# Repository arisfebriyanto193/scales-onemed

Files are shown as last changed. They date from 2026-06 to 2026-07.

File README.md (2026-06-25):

# scales-onemed

## Dokumentasi hardware: ./hadware.md

## Cara Menjalankan Program

### 1. Persiapan Database & Backend
Pastikan MySQL sudah berjalan di komputer Anda.

1. Buka terminal dan masuk ke folder `backend`:
   ```bash
   cd backend
   ```
2. Install semua dependencies:
   ```bash
   npm install
   ```
3. Buat file `.env` berdasarkan file contoh (salin isi `.env.example` ke file baru bernama `.env`):
   ```bash
   cp .env.example .env
   ```
   *Sesuaikan konfigurasi database (DB_USER, DB_PASSWORD, dll) di file `.env` jika diperlukan.*
4. Jalankan migrasi database untuk membuat tabel dan data awal (seeding):
   ```bash
   node migrations/run_migrations.js
   ```
5. Jalankan server backend:
   ```bash
   npm run dev
   ```
   *(Backend akan berjalan di port yang ditentukan di `.env`, biasanya `http://localhost:5000`)*

### 2. Persiapan Frontend
Buka tab terminal baru untuk menjalankan frontend.

1. Masuk ke folder `frontend`:
   ```bash
   cd frontend
   ```
2. Install semua dependencies:
   ```bash
   npm install
   ```
3. Pastikan ada file `.env.local` (jika diperlukan) untuk mengatur URL API backend (contoh: `NEXT_PUBLIC_API_URL=http://localhost:5000/api`).
4. Jalankan aplikasi frontend:
   ```bash
   npm run dev
   ```
   *(Frontend akan berjalan di port default Next.js, biasanya `http://localhost:3000`)*

Sekarang Anda bisa mengakses aplikasi melalui browser di `http://localhost:3000`.

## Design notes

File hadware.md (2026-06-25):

# Dokumentasi Hardware: Sistem Timbangan Pintar (ESP-A & ESP-B)

Dokumen ini menjelaskan arsitektur, hubungan, dan alur kerja antara dua mikrokontroler ESP32 (`espA` dan `espB`) yang digunakan dalam sistem timbangan pintar terintegrasi RFID dan IoT.

## 1. Hubungan ESP-A dan ESP-B

Kedua modul ESP32 ini memiliki peran yang dipisah (decoupled) agar kinerja sistem lebih stabil dan tidak saling membebani:
*   **ESP-A (Bluetooth Gateway):** Dikhususkan untuk menangani komunikasi Bluetooth Low Energy (BLE) yang seringkali intensif dan membutuhkan *real-time scanning*.
*   **ESP-B (Main Controller & IoT):** Berfungsi sebagai otak utama yang mengurus antarmuka pengguna (OLED), pembacaan identitas (RFID), dan komunikasi dua arah ke server (WiFi & WebSocket).

**Jalur Komunikasi:**
Kedua ESP ini berkomunikasi satu arah menggunakan pin **Serial UART (Hardware Serial2)**. 
*   **ESP-A (TX: GPIO17)** ──Kabel Data──> **ESP-B (RX: GPIO16)**
*   **ESP-A (GND)** ────────Kabel GND───> **ESP-B (GND)**

---

## 2. Skema Pin dan Wiring (Pinout)
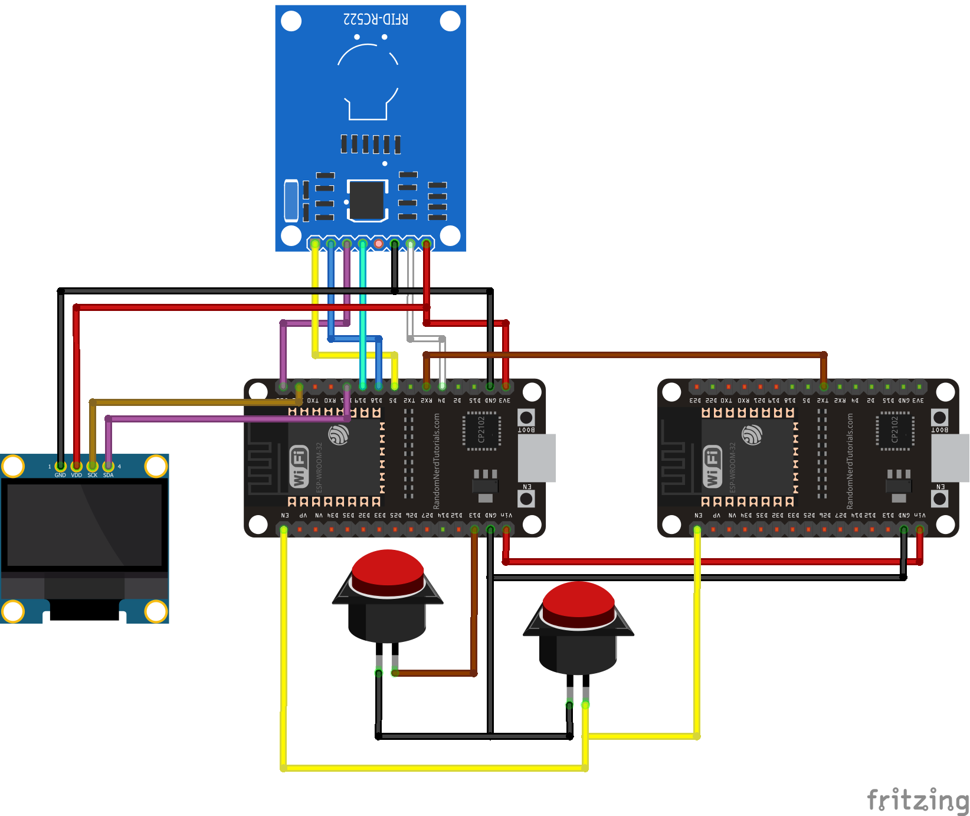
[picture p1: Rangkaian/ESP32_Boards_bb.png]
Rangkaian


Sistem ini menggunakan dua mikrokontroler ESP32 dengan pengkabelan sebagai berikut:

### Komunikasi Antar ESP32 (UART)
| ESP-A (Bluetooth) | ESP-B (Main Controller) | Keterangan |
| :--- | :--- | :--- |
| TX (GPIO 17) | RX (GPIO 16) | Mengirim data pengukuran |
| RX (GPIO 16) | TX (GPIO 17) | (Opsional, saat ini hanya searah) |
| GND | GND | Wajib disambung agar referensi tegangan sama |

### Modul RFID (RC522) -> ESP-B
Komunikasi menggunakan antarmuka **SPI**.
| Pin RC522 | Pin ESP-B | Keterangan |
| :--- | :--- | :--- |
| SDA / SS | GPIO 5 | Chip Select / Slave Select |
| SCK | GPIO 18 | Serial Clock |
| MOSI | GPIO 23 | Master Out Slave In |
| MISO | GPIO 19 | Master In Slave Out |
| RST | GPIO 4 | Reset (Jangan gunakan 22 karena dipakai OLED) |
| 3.3V | 3.3V | Power (Tegangan wajib 3.3V) |
| GND | GND | Ground |

### Layar OLED (SH1106 1.3" 128x64) -> ESP-B
Komunikasi menggunakan antarmuka **I2C**.
| Pin OLED | Pin ESP-B | Keterangan |
| :--- | :--- | :--- |
| SDA | GPIO 21 | Serial Data |
| SCL | GPIO 22 | Serial Clock |
| VCC | 3.3V | Power |
| GND | GND | Ground |

### Tombol (Push Button) -> ESP-B
| Pin Tombol | Pin ESP-B | Keterangan |
| :--- | :--- | :--- |
| Kaki 1 | GPIO 13 | Pin Input Pullup (Tombol HOLD/Reset) |
| Kaki 2 | GND | Trigger aktif LOW saat ditekan |

---

## 3. Fungsi dan Alur Kerja ESP-A (Pengambil Data BLE)

File: `espA.ino`

1.  **Scanning & Koneksi BLE:** ESP-A secara terus-menerus memindai perangkat BLE di sekitarnya untuk mencari timbangan dengan nama `SENSSUN Growth`. Setelah ditemukan, ESP-A akan melakukan koneksi ke perangkat tersebut.
2.  **Berlangganan Data (Notify):** Setelah terhubung, ESP-A mendengarkan (subscribe) pada karakteristik khusus (UUID: `0000fff1...`) untuk menerima notifikasi secara otomatis setiap kali timbangan mengukur atau datanya stabil.
3.  **Parsing Data Mentah (Hex):** Saat data masuk (`notifyCallback`), ESP-A menerima *array of bytes* (`uint8_t* data`) dari timbangan. Susunan data *byte* dari timbangan diurai sebagai berikut:
    *   **Berat Badan (kg):** Diambil dari index ke-2 dan ke-3 dalam *array* data (`data[2]` dan `data[3]`). Dua *byte* tersebut digabungkan (di-*shift* 8 bit) menjadi satu angka `uint16_t`, lalu dibagi `1000.0f` untuk mendapatkan angka aktual dalam satuan kilogram (kg).
    *   **Tinggi Badan (cm):** Diambil dari index ke-6 dan ke-7 (`data[6]` dan `data[7]`). Sama seperti berat, dua *byte* ini digabungkan menjadi `uint16_t` lalu dibagi `10.0f` untuk mendapatkan angka dalam satuan sentimeter (cm).
    *   **Kalkulasi BMI:** ESP-A akan menghitung *Body Mass Index* secara internal menggunakan rumus standar `BMI = Berat(kg) / (Tinggi(m) * Tinggi(m))`.
4.  **Pengiriman via UART:** Data yang sudah matang dan mudah dibaca kemudian dirakit menjadi satu baris teks sederhana (contoh: `BERAT:15.200;TINGGI:102.5;BMI:14.5\n`) lalu dikirimkan ke ESP-B melalui pin TX UART.

---

## 4. Fungsi dan Alur Kerja ESP-B (Main Controller & IoT)

File: `espB.ino`

ESP-B adalah titik kumpul dari semua fitur perangkat keras dan pengirim data akhir ke *cloud*. Berikut adalah penjabaran fungsinya:

### A. Mengambil Data RFID (MFRC522)
*   Menggunakan antarmuka **SPI** (Pin SCK=18, MISO=19, MOSI=23, SS=5).
*   Secara terus-menerus memantau apakah ada kartu atau *tag* RFID anak yang ditempelkan ke sensor.
*   Jika terdeteksi, ia membaca **UID (Unique ID)** kartu tersebut. Terdapat mekanisme *cooldown* 3 detik agar kartu yang sama tidak terbaca berkali-kali secara instan saat ditahan.

### B. Menampilkan di Layar (OLED SH1106)
*   Menggunakan antarmuka **I2C** (SDA=21, SCL=22).
*   Layar berfungsi sebagai indikator visual yang dinamis:
    *   **Status Sistem:** Menampilkan status koneksi WiFi, koneksi WebSocket, alamat IP, atau Mode AP saat awal dinyalakan.
    *   **Identifikasi Kartu:** Menampilkan UID Kartu saat baru saja di-tap dan menunggu respon server.
    *   **Nama Anak:** Menampilkan nama anak (selama 10 detik) setelah mendapatkan balasan/konfirmasi dari server IoT.
    *   **Data Pengukuran:** Menampilkan *Berat, Tinggi, dan BMI* yang dikirim dari ESP-A. Layar ini tampil jika tidak sedang mengutamakan tampilan nama anak.

### C. Komunikasi IoT (WebSocket)
ESP-B terhubung ke server *backend* menggunakan protokol **WebSocket (Secure / WSS)**. Ini membuat pertukaran data terjadi secara *real-time* dan sangat cepat.
1.  **Kirim UID:** Saat RFID di-tap, UID langsung dilempar ke server (Topik: `.../idcard|UID`).
2.  **Menerima Nama Anak:** Server memeriksa UID tersebut di database. Jika terdaftar, server membalas (mengirim topik `.../childname`) berisi nama anak yang bersangkutan. ESP-B menangkap data ini dan menampilkannya di OLED.
3.  **Kirim Data Timbangan:** Saat ESP-B menerima data teks ukur dari ESP-A melalui UART, ESP-B akan memecah (parse) kembali teks tersebut. Jika sistem tidak sedang di-*pause* (tombol HOLD mati), data tersebut langsung disiarkan ke server WebSocket satu per satu untuk topik berat, tinggi, dan bmi. Halaman web/frontend yang juga terhubung ke WebSocket akan langsung berkedip menampilkan angka ukur tanpa perlu me-refresh halaman.

### D. Fitur Tambahan (Konfigurasi & Tombol Pintar)
*   **WiFiManager:** Jika ESP-B baru dipasang atau gagal terhubung ke router WiFi, ia otomatis membuat Hotspot (AP Mode) bernama `ESP32_PENTING_Config`. Anda dapat terhubung ke *hotspot* ini melalui HP untuk mengatur SSID dan Password WiFi baru, serta mengisi konfigurasi alamat Server IoT (Host, Port, Prefix Topik). Setingan ini tersimpan di memori internal ESP.
*   **Tombol Fisik (GPIO 13):**
    *   **Tekan Singkat (< 5 detik):** Mengaktifkan/mematikan fitur **HOLD**. Jika fitur HOLD aktif, data angka dari timbangan akan *ditahan* dan tidak akan terkirim ke server (berguna ketika anak sedang banyak bergerak di atas timbangan sehingga angkanya belum akurat).
    *   **Tekan Lama (> 10 detik):** Melakukan **Factory Reset WiFi**. Alat akan menghapus memori WiFi yang tersimpan lalu *restart* untuk masuk kembali ke mode AP.

---

## 5. Desain Case (Perangkat Keras)

Berikut adalah rancangan 3D dari wadah (*case*) untuk merakit komponen-komponen *hardware* ke dalam satu kesatuan sistem:

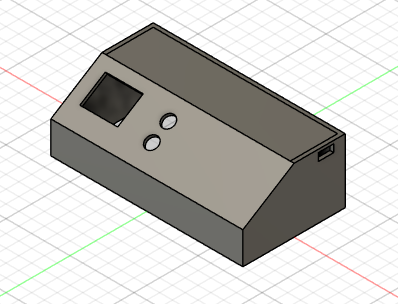
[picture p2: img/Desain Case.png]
Desain Case 1


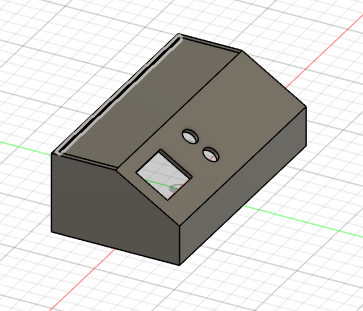
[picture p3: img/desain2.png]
Desain Case 2


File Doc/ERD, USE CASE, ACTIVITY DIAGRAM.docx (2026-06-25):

Login di Web

Manajemen User

Melihat Data Bayi

Keseluruhan di Web

Melihat Data

Bayi Pribadi

Mengedit Data Bayi

Keseluruhan di Web

Logout di Web

Melakukan Scan

RFID Bayi

Melakukan

Pengukuran Bayi

KADER

ADMIN

WARGA

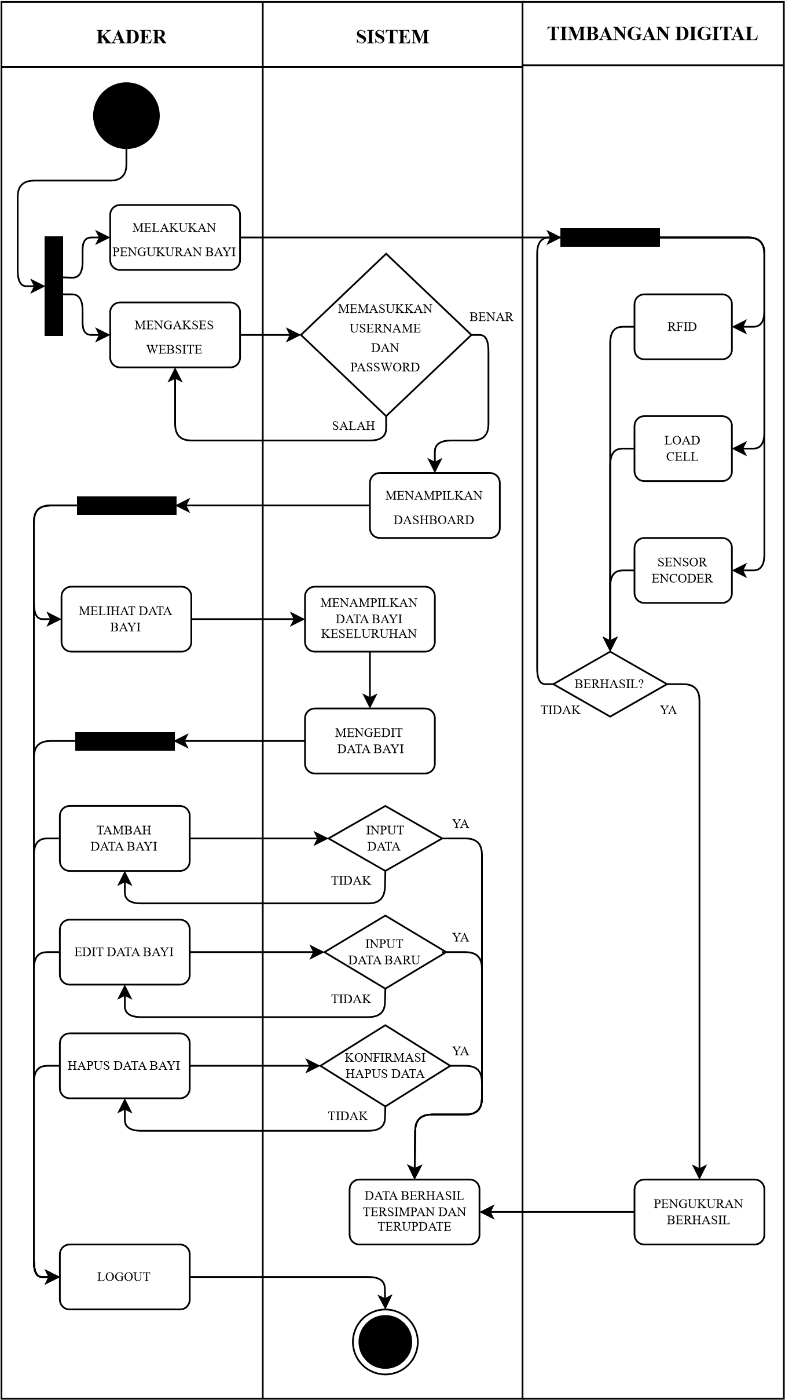
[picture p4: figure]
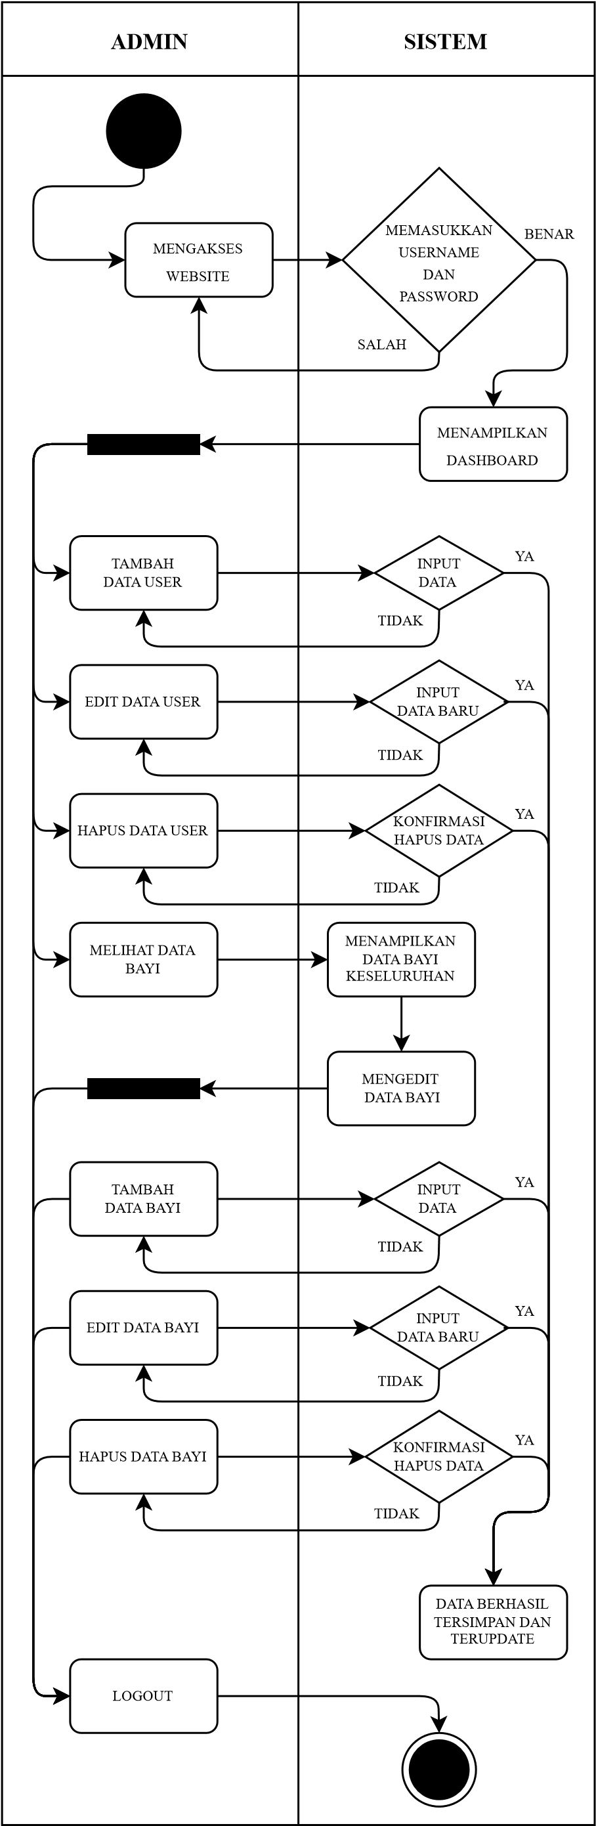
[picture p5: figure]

WARGA

SISTEM

MENGAKSES

WEBSITE

MELIHAT DATA

BAYI

MEMASUKKAN

USERNAME

DAN

PASSWORD

MENAMPILKAN

DASHBOARD

MENAMPILKAN

DATA BAYI

PRIBADI

DATA BERHASIL

TERSIMPAN DAN

TERUPDATE

LOGOUT

BENAR

SALAH

TIMBANGAN DIGITAL

MELAKUKAN

PENGUKURAN BAYI

RFID

LOAD

CELL

SENSOR

ENCODER

BERHASIL?

PENGUKURAN

BERHASIL

TIDAK

YA

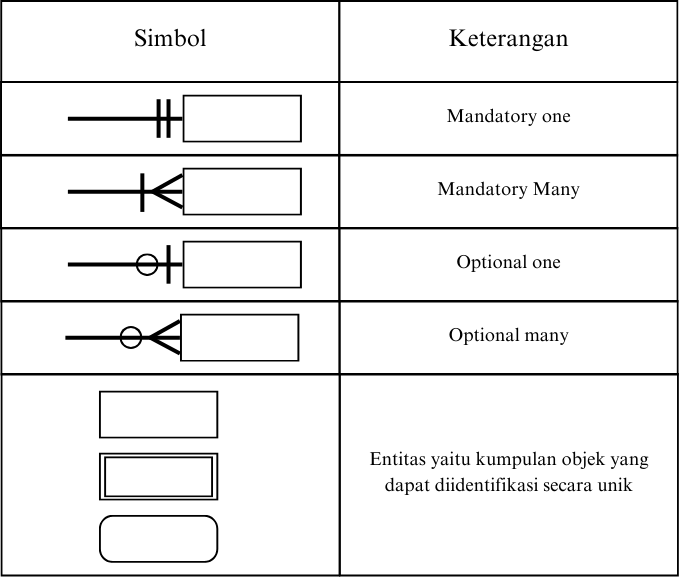
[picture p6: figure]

User

PK

id_user

nama

username

password

role

no.hp

Bayi

PK

id_bayi

FK

id_user

nama_bayi

tanggal lahir

jenis_kelamin

Pengukuran

PK

id_pengukuran

FK

id_bayi

FK

id_user

tanggal_pengukuran

berat_badan

tinggi_badan

standar_who

RFID Card

PK

id_rfid

FK

id_bayi

uid_rfid

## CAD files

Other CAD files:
3d File/ars.f3z

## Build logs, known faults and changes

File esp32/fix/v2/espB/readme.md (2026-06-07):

Target :
penambahan sensor rfid rc555, oled 0.96 inc 128x64

mengirimkan id card yg terbaca ke topic abcd/idcard, 

jadi idcard sebagai identitas anak , jadi ketika di tab kartu yg terdaftar di hlaman pengukurn akan langung terpilih anaknya dan di oled akan muncul namanya , koneksi semmuanaya ke websoket, dan jika belum terdaftar akan ada opsi menu tambahkan anak dengan id tersebut

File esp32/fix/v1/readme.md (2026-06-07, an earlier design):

mengambail data bb dan tb melalui esp A di kirimkan ke esp B dan di kirim ke websoket

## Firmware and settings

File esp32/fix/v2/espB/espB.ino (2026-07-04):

/**
 * ============================================================
 *  ESP32-B — UART Receiver + WebSocket Sender + RFID + OLED
 *  Alur: ESP32-A (BLE) → (UART TX→RX) → ESP32-B → WebSocket Server
 *        RFID RC522 → baca UID → WebSocket → Frontend → nama anak → OLED
 * ============================================================

 *  Koneksi UART dari ESP32-A:
 *    ESP32-A TX2 (GPIO17) ──→ ESP32-B RX2 (GPIO16)
 *    ESP32-A GND           ──→ ESP32-B GND
 *  Koneksi RFID RC522 (SPI):
 *    RC522 SDA/SS  ──→ GPIO5
 *    RC522 SCK     ──→ GPIO18
 *    RC522 MOSI    ──→ GPIO23
 *    RC522 MISO    ──→ GPIO19
 *    RC522 RST     ──→ GPIO4  (bukan GPIO22, itu untuk OLED SCL)
 *    RC522 3.3V    ──→ 3.3V
 *    RC522 GND     ──→ GND
 *
 *  Koneksi OLED SH1106 1.3" 128x64 (I2C):
 *    OLED SDA ──→ GPIO21
 *    OLED SCL ──→ GPIO22
 *    OLED VCC ──→ 3.3V
 *    OLED GND ──→ GND
 *
 *  Topic WebSocket:
 *    Publish  → "abcd/bb|xx.x"          (berat dari espA)
 *    Publish  → "abcd/tb|xxx.x"         (tinggi dari espA)
 *    Publish  → "abcd/bmi|xx.x"         (BMI dari espA)
 *    Publish  → "abcd/idcard|XXXXXXXX"  (UID RFID)
 *    Subscribe← "abcd/childname|Nama"   (nama anak dari frontend)
 *
 *  Library yang diperlukan (Library Manager):
 *    - WiFi (bawaan ESP32)
 *    - WebSockets by Markus Sattler
 *    - MFRC522 by GithubCommunity
 *    - Adafruit SH110X
 *    - Adafruit GFX Library
 * ============================================================
 */

#include <Arduino.h>
#include <WiFi.h>
#include <WebSocketsClient.h>
#include <SPI.h>
#include <MFRC522.h>
#include <Wire.h>
#include <Adafruit_GFX.h>
#include <Adafruit_SH110X.h>
#include <WiFiManager.h>
#include <Preferences.h>

// logo 

// 'Gemini_Generated_Image_sy3ij3sy3ij3sy3i', 128x64px
const unsigned char epd_bitmap_Gemini_Generated_Image_sy3ij3sy3ij3sy3i [] PROGMEM = {
	0xff, 0xff, 0xff, 0xff, 0xff, 0xff, 0xff, 0xff, 0xff, 0xff, 0xff, 0xff, 0xff, 0xff, 0xff, 0xff, 
	0xff, 0xff, 0xff, 0xff, 0xff, 0xff, 0xff, 0xff, 0xff, 0xff, 0xff, 0xff, 0xff, 0xff, 0xff, 0xff, 
	0xff, 0xff, 0xff, 0xff, 0xff, 0xff, 0xff, 0xff, 0xff, 0xff, 0xff, 0xff, 0xff, 0xff, 0xff, 0xff, 
	0xff, 0xff, 0xff, 0xff, 0xff, 0xff, 0xff, 0xff, 0xff, 0xff, 0xff, 0xff, 0xff, 0xff, 0xff, 0xff, 
	0xff, 0xff, 0xff, 0xff, 0xff, 0xff, 0xff, 0xff, 0xff, 0xff, 0xff, 0xff, 0xff, 0xff, 0xff, 0xff, 
	0xff, 0xff, 0xff, 0xff, 0xff, 0xff, 0xff, 0xff, 0xff, 0xff, 0xff, 0xff, 0xff, 0xff, 0xff, 0xff, 
	0xff, 0xff, 0xff, 0xff, 0xff, 0xff, 0xff, 0xff, 0xff, 0xff, 0xff, 0xff, 0xff, 0xff, 0xff, 0xff, 
	0xff, 0xff, 0xff, 0xff, 0xff, 0xff, 0xff, 0xff, 0xff, 0xff, 0xff, 0xff, 0xff, 0xff, 0xff, 0xff, 
	0xff, 0xff, 0xff, 0xff, 0xff, 0xff, 0xff, 0xfe, 0x7f, 0xff, 0xff, 0xff, 0xff, 0xff, 0xff, 0xff, 
	0xff, 0xff, 0xff, 0xff, 0xff, 0xff, 0xff, 0xfc, 0x1f, 0xff, 0xff, 0xff, 0xff, 0xff, 0xff, 0xff, 
	0xff, 0xff, 0xff, 0xff, 0xff, 0xff, 0xff, 0xf8, 0x1f, 0xff, 0xff, 0xff, 0xff, 0xff, 0xff, 0xff, 
	0xff, 0xff, 0xff, 0xff, 0xff, 0xff, 0xff, 0xf0, 0x0f, 0xff, 0xff, 0xff, 0xff, 0xff, 0xff, 0xff, 
	0xff, 0xff, 0xff, 0xff, 0xff, 0xff, 0xff, 0xe0, 0x07, 0xff, 0xff, 0xff, 0xff, 0xff, 0xff, 0xff, 
	0xff, 0xff, 0xff, 0xff, 0xff, 0xff, 0xff, 0xc0, 0x03, 0xff, 0xff, 0xff, 0xff, 0xff, 0xff, 0xff, 
	0xff, 0xff, 0xff, 0xff, 0xff, 0xff, 0xff, 0x80, 0x00, 0xff, 0xff, 0xff, 0xff, 0xff, 0xff, 0xff, 
	0xff, 0xff, 0xff, 0xff, 0xff, 0xff, 0xff, 0x00, 0x00, 0xff, 0xff, 0xff, 0xff, 0xff, 0xff, 0xff, 
	0xff, 0xff, 0xff, 0xff, 0xff, 0xff, 0xfc, 0x00, 0x00, 0x3f, 0xff, 0xff, 0xff, 0xff, 0xff, 0xff, 
	0xff, 0xff, 0xff, 0xff, 0xff, 0xff, 0xf8, 0x00, 0x00, 0x3f, 0xff, 0xff, 0xff, 0xff, 0xff, 0xff, 
	0xff, 0xff, 0xff, 0xff, 0xff, 0xff, 0xf0, 0x00, 0x00, 0x0f, 0xff, 0xff, 0xff, 0xff, 0xff, 0xff, 
	0xff, 0xff, 0xff, 0xff, 0xff, 0xff, 0xe0, 0x00, 0x00, 0x07, 0xff, 0xff, 0xff, 0xff, 0xff, 0xff, 
	0xff, 0xff, 0xff, 0xff, 0xff, 0xff, 0xc0, 0x38, 0x00, 0x03, 0xff, 0xff, 0xff, 0xff, 0xff, 0xff, 
	0xff, 0xff, 0xff, 0xff, 0xff, 0xff, 0x80, 0x7e, 0x00, 0x01, 0xff, 0xff, 0xff, 0xff, 0xff, 0xff, 
	0xff, 0xff, 0xff, 0xff, 0xff, 0xff, 0x00, 0xfe, 0x00, 0x00, 0xff, 0xff, 0xff, 0xff, 0xff, 0xff, 
	0xff, 0xff, 0xff, 0xff, 0xff, 0xfe, 0x01, 0xff, 0x00, 0x00, 0x7f, 0xff, 0xff, 0xff, 0xff, 0xff, 
	0xff, 0xff, 0xff, 0xff, 0xff, 0xfc, 0x01, 0xff, 0x00, 0x00, 0x3f, 0xff, 0xff, 0xff, 0xff, 0xff, 
	0xff, 0xff, 0xff, 0xff, 0xff, 0xf8, 0x01, 0xff, 0x00, 0x00, 0x1f, 0xff, 0xff, 0xff, 0xff, 0xff, 
	0xff, 0xff, 0xff, 0xff, 0xff, 0xf0, 0x01, 0xff, 0x00, 0x00, 0x0f, 0xff, 0xff, 0xff, 0xff, 0xff, 
	0xff, 0xff, 0xff, 0xff, 0xff, 0xe0, 0x00, 0xfe, 0x00, 0x00, 0x07, 0xff, 0xff, 0xff, 0xff, 0xff, 
	0xff, 0xff, 0xff, 0xff, 0xff, 0xe0, 0x03, 0xfc, 0x00, 0x00, 0x07, 0xff, 0xff, 0xff, 0xff, 0xff, 
	0xff, 0xff, 0xff, 0xff, 0xff, 0xfc, 0x1f, 0xf8, 0x0f, 0x80, 0x3f, 0xff, 0xff, 0xff, 0xff, 0xff, 
	0xff, 0xff, 0xff, 0xff, 0xff, 0xfc, 0x3f, 0xfc, 0x1f, 0xc0, 0x3f, 0xff, 0xff, 0xff, 0xff, 0xff, 
	0xff, 0xff, 0xff, 0xff, 0xff, 0xfc, 0x7f, 0xfe, 0x3f, 0xe0, 0x3f, 0xff, 0xff, 0xff, 0xff, 0xff, 
	0xff, 0xff, 0xff, 0xff, 0xff, 0xfc, 0x7f, 0xfe, 0x3f, 0xe0, 0x3f, 0xff, 0xff, 0xff, 0xff, 0xff, 
	0xff, 0xff, 0xff, 0xff, 0xff, 0xfc, 0xff, 0xfe, 0x3f, 0xe0, 0x3f, 0xff, 0xff, 0xff, 0xff, 0xff, 
	0xff, 0xff, 0xff, 0xff, 0xff, 0xfc, 0xff, 0xf8, 0x1f, 0xe0, 0x3f, 0xff, 0xff, 0xff, 0xff, 0xff, 
	0xff, 0xff, 0xff, 0xff, 0xff, 0xfc, 0xff, 0xf3, 0xff, 0xc0, 0x3f, 0xff, 0xff, 0xff, 0xff, 0xff, 
	0xff, 0xff, 0xff, 0xff, 0xff, 0xfe, 0xff, 0xef, 0xff, 0xfc, 0x3f, 0xff, 0xff, 0xff, 0xff, 0xff, 
	0xff, 0xff, 0xff, 0xff, 0xff, 0xfe, 0xff, 0xef, 0xff, 0xfe, 0x7f, 0xff, 0xff, 0xff, 0xff, 0xff, 
	0xff, 0xff, 0xff, 0xff, 0xff, 0xfe, 0xff, 0xdf, 0xff, 0xff, 0x7f, 0xff, 0xff, 0xff, 0xff, 0xff, 
	0xff, 0xff, 0xff, 0xff, 0xff, 0xfe, 0xff, 0xdf, 0xff, 0xff, 0x7f, 0xff, 0xff, 0xff, 0xff, 0xff, 
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
};

// Array of all bitmaps for convenience. (Total bytes used to store images in PROGMEM = 1040)
const int epd_bitmap_allArray_LEN = 1;
const unsigned char* epd_bitmap_allArray[1] = {
	epd_bitmap_Gemini_Generated_Image_sy3ij3sy3ij3sy3i
};

Preferences preferences;

// ─────────────────── Konfigurasi WebSocket ──────────────────
String ws_host;
String ws_path;
int    ws_port;
String topic_prefix;

// ─────────────────── Topic WebSocket ────────────────────────
String TOPIC_BERAT;
String TOPIC_TINGGI;
String TOPIC_BMI;
String TOPIC_IDCARD;
String TOPIC_CHILDNAME;

bool shouldSaveConfig = false;
void saveConfigCallback() {
  shouldSaveConfig = true;
}

// ─────────────────── Konfigurasi Tombol HOLD/RESET ──────────
#define HOLD_PIN      13    // GPIO 13 (aman, bukan strapping pin)
#define DEBOUNCE_MS   50    // minimal tahan sebelum dihitung (ms)
unsigned long buttonPressTime = 0;
bool isButtonPressed = false;
bool isHold = false;
// ─────────────────── Konfigurasi UART dari espA ─────────────
#define UART_BAUD   115200
#define UART_RX_PIN 16
#define UART_TX_PIN 17

// ─────────────────── Konfigurasi RFID RC522 (SPI) ───────────
#define RFID_SS_PIN  5
#define RFID_RST_PIN 4
MFRC522 rfid(RFID_SS_PIN, RFID_RST_PIN);

// ─────────────────── Konfigurasi OLED 128x64 (I2C) ──────────
#define OLED_WIDTH  128
#define OLED_HEIGHT 64
#define OLED_ADDR   0x3C
Adafruit_SH1106G oled(OLED_WIDTH, OLED_HEIGHT, &Wire, -1);

// ─────────────────── State ──────────────────────────────────
WebSocketsClient webSocket;
bool wsConnected   = false;
String uartBuffer  = "";

// RFID State
String lastUID         = "";
unsigned long uidTimestamp = 0;
#define UID_COOLDOWN_MS 3000   // minimal jarak tap kartu yang sama

// Nama anak dari frontend (via WS)
String childName = "";
unsigned long childNameTimestamp = 0;
#define CHILDNAME_DISPLAY_MS 10000  // tampilkan nama selama 10 detik

// ─────────────────── Helper: UID → String HEX ────────────────
String getUIDString(MFRC522& reader) {
  String uid = "";
  for (byte i = 0; i < reader.uid.size; i++) {
    if (reader.uid.uidByte[i] < 0x10) uid += "0";
    uid += String(reader.uid.uidByte[i], HEX);
  }
  uid.toUpperCase();
  return uid;
}

// ─────────────────── OLED Helpers ────────────────────────────
void oledClear() {
  oled.clearDisplay();
  oled.setTextColor(SH110X_WHITE);
}

void oledTitle(const char* title) {
  oled.setTextSize(1);
  oled.setCursor(0, 0);
  oled.println(title);
  oled.drawLine(0, 10, OLED_WIDTH, 10, SH110X_WHITE);
}

// Tampilan: status sistem
void oledShowStatus(const char* line1, const char* line2 = "", const char* line3 = "") {
  oledClear();
  oledTitle("ESP32-B  PENTING");
  oled.setTextSize(1);
  oled.setCursor(0, 14);
  oled.println(line1);
  oled.setCursor(0, 26);
  oled.println(line2);
  oled.setCursor(0, 38);
  oled.println(line3);
  oled.display();
}
// Tampilan: UID kartu terdeteksi
void oledShowUID(const String& uid) {
  oledClear();
  oledTitle("Kartu Terdeteksi");
  oled.setTextSize(1);
  oled.setCursor(0, 14);
  oled.println("UID:");
  oled.setTextSize(1);
  oled.setCursor(0, 26);
  oled.println(uid);
  oled.setCursor(0, 40);
  oled.println("Mencari data...");
  oled.display();
}

// Tampilan: nama anak ditemukan
void oledShowChild(const String& uid, const String& nama) {
  oledClear();
  oledTitle("Anak Teridentifikasi");
  oled.setTextSize(1);
  oled.setCursor(0, 14);
  oled.println("Nama:");
  oled.setTextSize(1);
  oled.setCursor(0, 26);

  // Wrap teks jika nama panjang
  if (nama.length() <= 21) {
    oled.println(nama);
  } else {
    oled.println(nama.substring(0, 21));
    oled.setCursor(0, 36);
    oled.println(nama.substring(21, 42));
  }

  oled.setTextSize(1);
  oled.setCursor(0, 52);
  oled.print("UID: ");
  oled.print(uid.length() > 10 ? uid.substring(0, 10) + ".." : uid);
  oled.display();
}

// Tampilan: kartu tidak terdaftar
void oledShowUnknown(const String& uid) {
  oledClear();
  oledTitle("Kartu Tidak Dikenal");
  oled.setTextSize(1);
  oled.setCursor(0, 14);
  oled.println("UID:");
  oled.setCursor(0, 26);
  oled.println(uid);
  oled.setCursor(0, 40);
  oled.println("Daftar di website!");
  oled.display();
}

// Tampilan: Data pengukuran (BB, TB, BMI)
void oledShowData(float berat, float tinggi, float bmi) {
  oledClear();
  oledTitle("Hasil Pengukuran");
  
  oled.setTextSize(1);
  oled.setCursor(0, 16);
  oled.print("Berat  : ");
  oled.print(berat, 2);
  oled.println(" kg");

  oled.setCursor(0, 30);
  oled.print("Tinggi : ");
  oled.print(tinggi, 1);
  oled.println(" cm");

  oled.setCursor(0, 44);
  oled.print("BMI    : ");
  oled.println(bmi, 1);
  
  oled.display();
}

// ─────────────────── Callback WiFiManager AP Mode ───────────
void configModeCallback(WiFiManager *myWiFiManager) {
  oledShowStatus("AP Mode", myWiFiManager->getConfigPortalSSID().c_str(), WiFi.softAPIP().toString().c_str());
  Serial.println("[WIFI] Masuk AP Mode");
  Serial.println(myWiFiManager->getConfigPortalSSID());
}

// ─────────────────── Callback WebSocket ─────────────────────
void webSocketEvent(WStype_t type, uint8_t* payload, size_t length) {
  switch (type) {
    case WStype_CONNECTED:
      wsConnected = true;
      Serial.println("✅ [WS] WebSocket terhubung");

      // Subscribe topic nama anak (dikirim balik dari frontend)
      webSocket.sendTXT(
        String("{\"action\":\"subscribe\",\"topic\":\"") + TOPIC_CHILDNAME + "\"}"
      );
      oledShowStatus("WiFi: OK", "WS: Terhubung", "Tap kartu RFID...");
      break;

    case WStype_DISCONNECTED:
      wsConnected = false;
      Serial.println("❌ [WS] WebSocket terputus");
      oledShowStatus("WS: Terputus", "Reconnecting...", "");
      break;

    case WStype_TEXT: {
      String msg = String((char*)payload);
      Serial.println("📨 [WS] Pesan: " + msg);

      // ── Format "topic|value" ──────────────────────────────
      if (msg.indexOf('|') >= 0) {
        int sep = msg.indexOf('|');
        String topic = msg.substring(0, sep);
        String value = msg.substring(sep + 1);
        topic.trim(); value.trim();

        if (topic == TOPIC_CHILDNAME) {
          childName = value;
          childNameTimestamp = millis();
          Serial.println("👶 Nama anak: " + childName);
          oledShowChild(lastUID, childName);
        }
        return;
      }

      // ── Format JSON {"topic":"...","payload":"..."} ───────
      // Parsing manual ringan (tanpa library JSON besar)
      if (msg.indexOf("\"topic\"") >= 0 && msg.indexOf("\"payload\"") >= 0) {
        // Ekstrak topic
        int tStart = msg.indexOf("\"topic\":\"") + 9;
        int tEnd   = msg.indexOf("\"", tStart);
        String topic = (tStart > 9 && tEnd > tStart) ? msg.substring(tStart, tEnd) : "";

        // Ekstrak payload
        int pStart = msg.indexOf("\"payload\":\"") + 11;
        int pEnd   = msg.indexOf("\"", pStart);
        String value = (pStart > 11 && pEnd > pStart) ? msg.substring(pStart, pEnd) : "";

        if (topic == TOPIC_CHILDNAME && value.length() > 0) {
          childName = value;
          childNameTimestamp = millis();
          Serial.println("👶 Nama anak (JSON): " + childName);
          oledShowChild(lastUID, childName);
        }
      }
      break;
    }

    case WStype_ERROR:
      Serial.println("⚠️  [WS] Error WebSocket");
      break;

    default:
      break;
  }
}

// ─────────────────── Parse string UART ──────────────────────
// Format: "BERAT:xx.x;TINGGI:xxx.x;BMI:xx.x"
bool parseUartLine(const String& line, float& berat, float& tinggi, float& bmi) {
  int idxB = line.indexOf("BERAT:");
  int idxT = line.indexOf(";TINGGI:");
  int idxM = line.indexOf(";BMI:");

  if (idxB < 0 || idxT < 0 || idxM < 0) return false;

  berat  = line.substring(idxB + 6, idxT).toFloat();
  tinggi = line.substring(idxT + 8, idxM).toFloat();
  bmi    = line.substring(idxM + 5).toFloat();

  return true;
}

// ─────────────────── Kirim data sensor ke WebSocket ─────────
void sendToWebSocket(float berat, float tinggi, float bmi) {
  if (!wsConnected) {
    Serial.println("[WS] Belum terhubung, data tidak dikirim.");
    return;
  }

  String msgBerat  = String(TOPIC_BERAT)  + "|" + String(berat, 3);
  String msgTinggi = String(TOPIC_TINGGI) + "|" + String(tinggi, 1);
  String msgBMI    = String(TOPIC_BMI)    + "|" + String(bmi, 1);

  webSocket.sendTXT(msgBerat);
  webSocket.sendTXT(msgTinggi);
  webSocket.sendTXT(msgBMI);

  Serial.println("📤 [WS] " + msgBerat);
  Serial.println("📤 [WS] " + msgTinggi);
  Serial.println("📤 [WS] " + msgBMI);
}

// ─────────────────── Kirim UID RFID ke WebSocket ─────────────
void sendRFIDtoWebSocket(const String& uid) {
  if (!wsConnected) {
    Serial.println("[WS] Belum terhubung, UID tidak dikirim.");
    return;
  }
  String msg = String(TOPIC_IDCARD) + "|" + uid;
  webSocket.sendTXT(msg);
  Serial.println("📤 [WS RFID] " + msg);
}
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
void loop() {
  // ── Handle Tombol (Dual Function) ────────────────────────
  // Tahan < 5 detik saat lepas → toggle HOLD
  // Tahan >= 10 detik saat masih tertekan → reset WiFi ke AP mode
  bool btnNow = (digitalRead(HOLD_PIN) == LOW);
  if (btnNow) {
    if (!isButtonPressed) {
      // Catat waktu mulai tekan (debounce akan dicek saat lepas)
      buttonPressTime = millis();
      isButtonPressed = true;
    } else {
      unsigned long held = millis() - buttonPressTime;
      // Hanya proses jika sudah melewati debounce (pin benar-benar tertekan)
      if (held >= DEBOUNCE_MS && held >= 10000) {
        // Tahan 10 detik → reset WiFi
        isButtonPressed = false;
        Serial.println("[BTN] Tahan 10 detik → Reset WiFi");
        oledShowStatus("Reset WiFi", "Lupakan WiFi...", "AP Mode aktif");
        WiFiManager wifiManager;
        wifiManager.resetSettings();
        delay(2000);
        ESP.restart();
      }
    }
  } else {
    if (isButtonPressed) {
      unsigned long held = millis() - buttonPressTime;
      isButtonPressed = false;
      // Abaikan jika terlalu singkat (noise/glitch < debounce)
      if (held >= DEBOUNCE_MS && held < 5000) {
        // Lepas < 5 detik (dan bukan glitch) → toggle HOLD
        isHold = !isHold;
        Serial.println(isHold ? "[BTN] HOLD ON" : "[BTN] HOLD OFF");
        if (isHold) {
          oledShowStatus("HOLD AKTIF", "Data ditahan", "Tekan lagi utk lanjut");
        } else {
          oledShowStatus("HOLD MATI", "Data mengalir", "WS: Terhubung");
        }
      }
      // antara 5-10 detik → tidak ada aksi
    }
  }

  // ── Handle WebSocket ──────────────────────────────────────
  webSocket.loop();

  // ── Reset nama anak setelah timeout display ───────────────
  if (childName.length() > 0 && millis() - childNameTimestamp > CHILDNAME_DISPLAY_MS) {
    childName = "";
    if (wsConnected) {
      oledShowStatus("WiFi: OK", "WS: Terhubung", "Tap kartu RFID...");
    }
  }

  // ── Scan RFID ─────────────────────────────────────────────
  if (rfid.PICC_IsNewCardPresent() && rfid.PICC_ReadCardSerial()) {
    String uid = getUIDString(rfid);
    rfid.PICC_HaltA();
    rfid.PCD_StopCrypto1();

    // Cooldown: hindari kirim UID berulang saat kartu ditahan
    bool isSameUID    = (uid == lastUID);
    bool withinCooldown = (millis() - uidTimestamp < UID_COOLDOWN_MS);

    if (!isSameUID || !withinCooldown) {
      lastUID = uid;
      uidTimestamp = millis();
      childName = "";  // reset nama lama

      Serial.println("🎫 [RFID] Kartu terdeteksi: " + uid);
      oledShowUID(uid);
      sendRFIDtoWebSocket(uid);
    }
  }

  // ── Baca data dari espA via UART ──────────────────────────
  while (Serial2.available()) {
    char c = (char)Serial2.read();
    if (c == '\n') {
      uartBuffer.trim();
      if (uartBuffer.length() > 0) {
        Serial.println("[UART] Diterima: " + uartBuffer);

        float berat = 0, tinggi = 0, bmi = 0;
        if (parseUartLine(uartBuffer, berat, tinggi, bmi)) {
          Serial.printf("[PARSE] Berat=%.3f kg | Tinggi=%.1f cm | BMI=%.1f\n",
                        berat, tinggi, bmi);
          if (!isHold) {
            sendToWebSocket(berat, tinggi, bmi);
            // Tampilkan di OLED jika tidak sedang menampilkan data anak
            if (childName.length() == 0) {
              oledShowData(berat, tinggi, bmi);
            }
          } else {
            Serial.println("[HOLD] Data diabaikan (Hold Aktif)");
          }
        } else {
          Serial.println("[PARSE] ⚠️  Format tidak dikenali: " + uartBuffer);
        }
      }
      uartBuffer = "";
    } else {
      uartBuffer += c;
    }
  }
  delay(10);
}

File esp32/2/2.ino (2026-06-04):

/**
 * ============================================================
 *  ESP32 BLE Client — SENSSUN GROWTH
 *  Framework : Arduino (ESP32 Arduino Core)
 *  Library   : BLE bawaan ESP32 Arduino Core
 * ============================================================
 *
 *  Target device  : SENSSUN GROWTH
 *  Service UUID   : 0000fff0-0000-1000-8000-00805f9b34fb
 *  Char RX (FFF1) : 0000fff1-0000-1000-8000-00805f9b34fb  (NOTIFY)
 *  Char TX (FFF2) : 0000fff2-0000-1000-8000-00805f9b34fb  (WRITE)
 *
 *  Format paket 13 byte:
 *    FF A5 [W_H] [W_L] [?] [?] [H_H] [H_L] [?] [?] [?] [SEQ] [CHK]
 *    Berat (kg)  = (byte[2]<<8 | byte[3]) / 1000.0
 *    Tinggi (cm) = (byte[6]<<8 | byte[7]) / 10.0
 * ============================================================
 */

#include <Arduino.h>
#include <BLEDevice.h>
#include <BLEUtils.h>
#include <BLEScan.h>
#include <BLEAdvertisedDevice.h>
#include <BLEClient.h>
#include <BLERemoteCharacteristic.h>/**
 * ============================================================
 *  ESP32 BLE Client — SENSSUN GROWTH
 *  Framework : Arduino (ESP32 Arduino Core)
 *  Library   : BLE bawaan ESP32 Arduino Core
 * ============================================================
 *
 *  Target device  : SENSSUN GROWTH
 *  Service UUID   : 0000fff0-0000-1000-8000-00805f9b34fb
 *  Char RX (FFF1) : 0000fff1-0000-1000-8000-00805f9b34fb  (NOTIFY)
 *  Char TX (FFF2) : 0000fff2-0000-1000-8000-00805f9b34fb  (WRITE)
 *
 *  Format paket 13 byte:
 *    FF A5 [W_H] [W_L] [?] [?] [H_H] [H_L] [?] [?] [?] [SEQ] [CHK]
 *    Berat (kg)  = (byte[2]<<8 | byte[3]) / 1000.0
 *    Tinggi (cm) = (byte[6]<<8 | byte[7]) / 10.0
 * ============================================================
 */

#include <Arduino.h>
#include <BLEDevice.h>
#include <BLEUtils.h>
#include <BLEScan.h>
#include <BLEAdvertisedDevice.h>
#include <BLEClient.h>
#include <BLERemoteCharacteristic.h>
#include <BLERemoteService.h>

// ───────────────────── Konfigurasi ──────────────────────────
static const char* TARGET_NAME   = "SENSSUN Growth";
static const char* SERVICE_UUID  = "0000fff0-0000-1000-8000-00805f9b34fb";
static const char* CHAR_RX_UUID  = "0000fff1-0000-1000-8000-00805f9b34fb";  // NOTIFY
static const char* CHAR_TX_UUID  = "0000fff2-0000-1000-8000-00805f9b34fb";  // WRITE
static const uint32_t SCAN_TIMEOUT_SEC = 15;
static const uint32_t RECONNECT_DELAY_MS = 5000;
// ─────────────────────────────────────────────────────────────

// ───────────────────── State global ─────────────────────────
static BLEClient*              pClient    = nullptr;
static BLERemoteCharacteristic* pCharRX   = nullptr;
static BLEAdvertisedDevice*    pTargetDev = nullptr;
static bool deviceFound    = false;
static bool isConnected    = false;
static bool doConnect      = false;
static bool doScan         = true;

// ───────────────── Parsing paket ────────────────────────────
void parseAndPrint(uint8_t* data, size_t len) {
  Serial.println("──────────────────────────────────────────────");

  // Cetak HEX mentah
  Serial.print("HEX: ");
  for (size_t i = 0; i < len; i++) {
    if (data[i] < 0x10) Serial.print("0");
    Serial.print(data[i], HEX);
    Serial.print(" ");
  }
  Serial.println();
  Serial.printf("LEN: %u\n", (unsigned)len);

  if (len < 8) {
    Serial.println("[!] Paket terlalu pendek, skip parse.");
    return;
  }

  uint16_t rawWeight = ((uint16_t)data[2] << 8) | data[3];
  uint16_t rawHeight = ((uint16_t)data[6] << 8) | data[7];

  float weightKg = rawWeight / 1000.0f;
  float heightCm = rawHeight / 10.0f;

  Serial.printf("Berat  : %.1f kg\n", weightKg);
  Serial.printf("Tinggi : %.1f cm\n", heightCm);

  // Hitung BMI jika data valid
  if (heightCm > 50.0f && weightKg > 1.0f) {
    float heightM = heightCm / 100.0f;
    float bmi = weightKg / (heightM * heightM);
    Serial.printf("BMI    : %.1f", bmi);
    if      (bmi < 18.5f) Serial.println("  (Kurus)");
    else if (bmi < 25.0f) Serial.println("  (Normal)");
    else if (bmi < 30.0f) Serial.println("  (Overweight)");
    else                  Serial.println("  (Obesitas)");
  }
}

// ───────────────── Callback notifikasi ──────────────────────
static void notifyCallback(
  BLERemoteCharacteristic* pChar,
  uint8_t* pData,
  size_t length,
  bool isNotify)
{
  parseAndPrint(pData, length);
}

// ───────────────── Callback koneksi ─────────────────────────
class ClientCallbacks : public BLEClientCallbacks {
  void onConnect(BLEClient* pclient) override {
    isConnected = true;
    Serial.println("[BLE] Terhubung.");
  }

  void onDisconnect(BLEClient* pclient) override {
    isConnected = false;
    doScan      = true;       // mulai scan ulang
    Serial.println("[BLE] Terputus. Akan scan ulang...");
  }
};

// ───────────────── Callback scan ────────────────────────────
class ScanCallbacks : public BLEAdvertisedDeviceCallbacks {
  void onResult(BLEAdvertisedDevice advertisedDevice) override {
    String devName = advertisedDevice.getName().c_str();
    if (devName.indexOf(TARGET_NAME) >= 0) {
      Serial.printf("[SCAN] Ditemukan: %s  (%s)\n",
        devName.c_str(),
        advertisedDevice.getAddress().toString().c_str());

      BLEDevice::getScan()->stop();
      pTargetDev  = new BLEAdvertisedDevice(advertisedDevice);
      deviceFound = true;
      doConnect   = true;
    }
  }
};

// ───────────────── Fungsi koneksi ───────────────────────────
bool connectToDevice() {
  Serial.printf("[BLE] Menghubungkan ke %s ...\n",
    pTargetDev->getAddress().toString().c_str());

  if (pClient != nullptr) {
    delete pClient;
    pClient = nullptr;
  }

  pClient = BLEDevice::createClient();
  pClient->setClientCallbacks(new ClientCallbacks());

  if (!pClient->connect(pTargetDev)) {
    Serial.println("[BLE] Gagal connect.");
    return false;
  }

  // Cari service FFF0
  BLERemoteService* pService = pClient->getService(BLEUUID(SERVICE_UUID));
  if (pService == nullptr) {
    Serial.printf("[BLE] Service %s tidak ditemukan.\n", SERVICE_UUID);
    pClient->disconnect();
    return false;
  }

  // Cari characteristic FFF1 (NOTIFY)
  pCharRX = pService->getCharacteristic(BLEUUID(CHAR_RX_UUID));
  if (pCharRX == nullptr) {
    Serial.printf("[BLE] Char RX %s tidak ditemukan.\n", CHAR_RX_UUID);
    pClient->disconnect();
    return false;
  }

  // Subscribe notifikasi
  if (pCharRX->canNotify()) {
    pCharRX->registerForNotify(notifyCallback);
    Serial.println("[BLE] Subscribe NOTIFY berhasil.");
  } else {
    Serial.println("[BLE] Char RX tidak support NOTIFY.");
    pClient->disconnect();
    return false;
  }

  Serial.println("══════════════════════════════════════════════");
  Serial.println("  ESP32 BLE Monitor SENSSUN GROWTH — aktif");
  Serial.printf ("  Device  : %s\n", pTargetDev->getName().c_str());
  Serial.printf ("  Address : %s\n", pTargetDev->getAddress().toString().c_str());
  Serial.println("  Menunggu data dari timbangan...");
  Serial.println("══════════════════════════════════════════════");

  return true;
}
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

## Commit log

2026-06-25 Update hardware.md with wiring diagram image
    Add image for wiring diagram in hardware documentation
2026-09-02 fix: make sidebar height 100% so logout button is visible on mobile
